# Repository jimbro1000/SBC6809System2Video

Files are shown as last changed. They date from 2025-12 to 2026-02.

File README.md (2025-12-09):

# SBC6309 Video Inspired by Acorn System 2 #

This started out as a reimplementation of the Acorn system 2 teletext card.
That design quickly went in the bin in favour or something closer to the
video implementation of the BBC Model A/B or Amstrad CPC464.

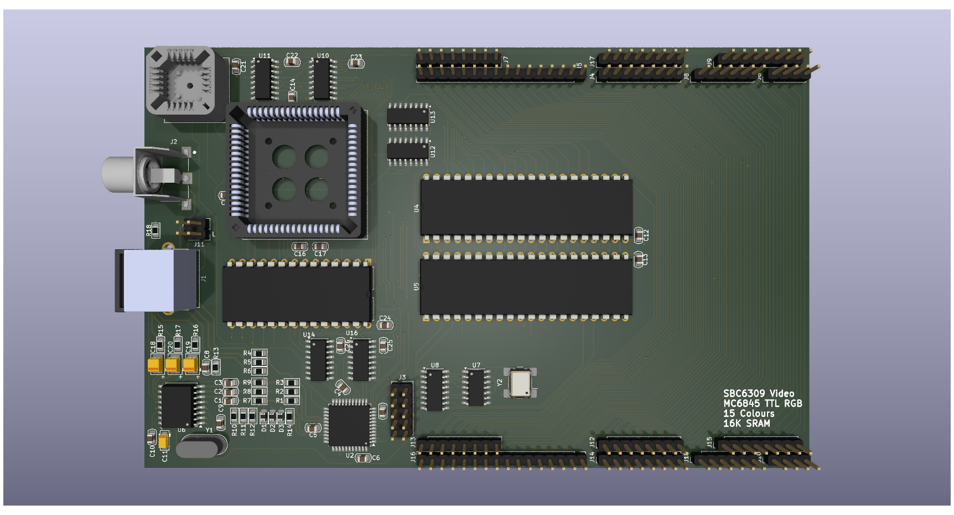
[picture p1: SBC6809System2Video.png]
Render of reproduction board


## Theory of Operation ##

The design is based around a MC6845 CRTC for video timing and sync generation.
This is supplemented with a MC6821 to provide additional control over 
variables outside of the CRTC capability (such as colour palette control)

The conversion of byte data into graphic output is handled by a small CPLD
generating TTL RGB (with a half-bright to facilitate 15 colours).

Optionally the RGB is converted to Chroma and Luma for S-video and Composite
(all in PAL format). Note the RGB doesn't have to be PAL timing but the 
composite will not operate correctly if the timing is abused. Conversion is
performed by a AD724JRZ encoder.

### Clocks ###

The pixel clock is generated on the board starting with a 32MHz oscillator,
this is divided down to 16, 8, 4 or 2MHz. At the same time the data clock is
fixed and synchronised at quarter of the pixel clock.

The choice of divider is controlled by the PIA. Changing the divider requires
the CRTC register values to be reset.

### Video Memory ###

To simplify the design the board uses 16K of dual-port SRAM, this decouples
the main clock of the computer from the video clock, allowing it to run out
of phase without repurcussions. While dual-port ram is expensive, the chip
used here can be obtained at a price comparable to regular SRAM (still more
expensive but not prohibitively so).

From the perspective of the host the video memory is just an 8K window, the
address range is paged via the PIA to expand to the full 16K.

### System Integration ###

The board uses a 16V8 GAL to integrate the board into the rest of the computer
for the purposes of mapping main bus addresses to the video ram and to the CRTC
and PIA.

The main video (RGB) output is through a 9-pin mini-din socket, this incorporates
stereo audio output not generated on this board. The signal can be injected via a
pair of two pin headers.

## Plans ##

### Text Mode ###

The objective is to create a single general purpose video board for the SBC6309
project which must include a text-only mode. To achieve this the board needs to
incorporate a character generator ROM. A set of 256 characters at 8 bytes per
character requires a 2K address space, the CRTC provides row addressing for up
to 32 bytes. Assuming the maximum the requirement increases to 8K but a 8 pixel
x 32 pixel character is of limited use. A more practical solution is to utilise
the 16 byte option and map the rows to 8, 10 or 12. An 8K rom would allow for two
different character sets, possibly at different row counts.

Switching between bitmap and character modes can be performed using a simple
74LS157 multiplexer (two required) depending on the mode. Graphic data can be mapped
to both the multiplexer directly (bitmap) or via the character rom (text).

### Larger Address Space ###

The 6845 can address a maximum of 512KB - way beyond the addressing capability
of the host. With an 8K window that 64 pages. Expanding to a 16K window would make 
this more digestable. The cost of dual-port ram would become excessive however to
take this to the maximum.

Increasing to 32K (or 64K) falls within reasonable design and cost limits.

The mechanism for expanding the address space is the same as used for text mode,
leveraging the row address registers. By adjusting the design for one, the other
becomes inherent.

Referring back to the BBC Model A/B and Amstrad CPC the same trick is used. In
the BBC the row address is effectively the lower 3 bits of the address so that
the bitmap proceeds vertically for 8 bytes before moving to the next horizontal
position. The Amstrad moves the row address on so that each row of video data
is consecutive but vertically jumps 8 rows before returning to the top (offset
by a row) and proceeding again

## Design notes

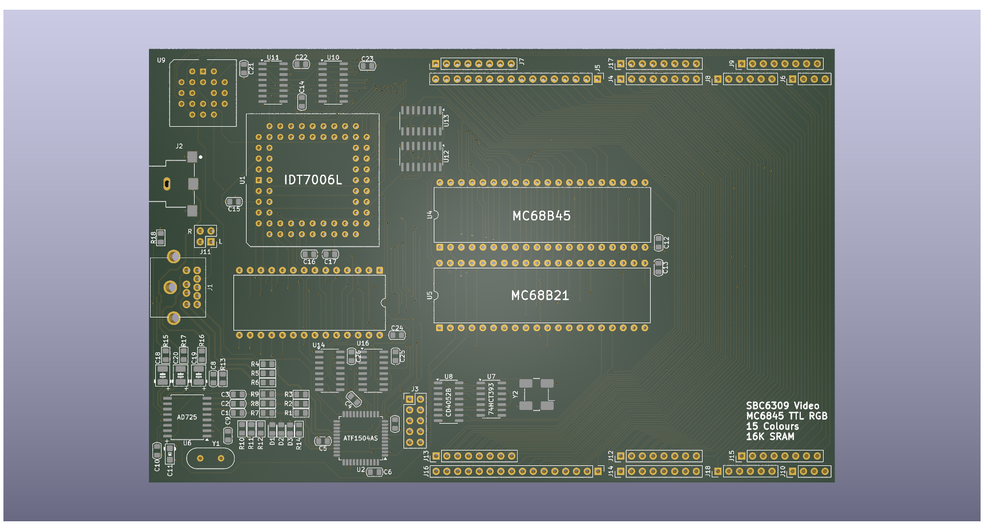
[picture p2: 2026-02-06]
SBC6809System2Video-bare.png

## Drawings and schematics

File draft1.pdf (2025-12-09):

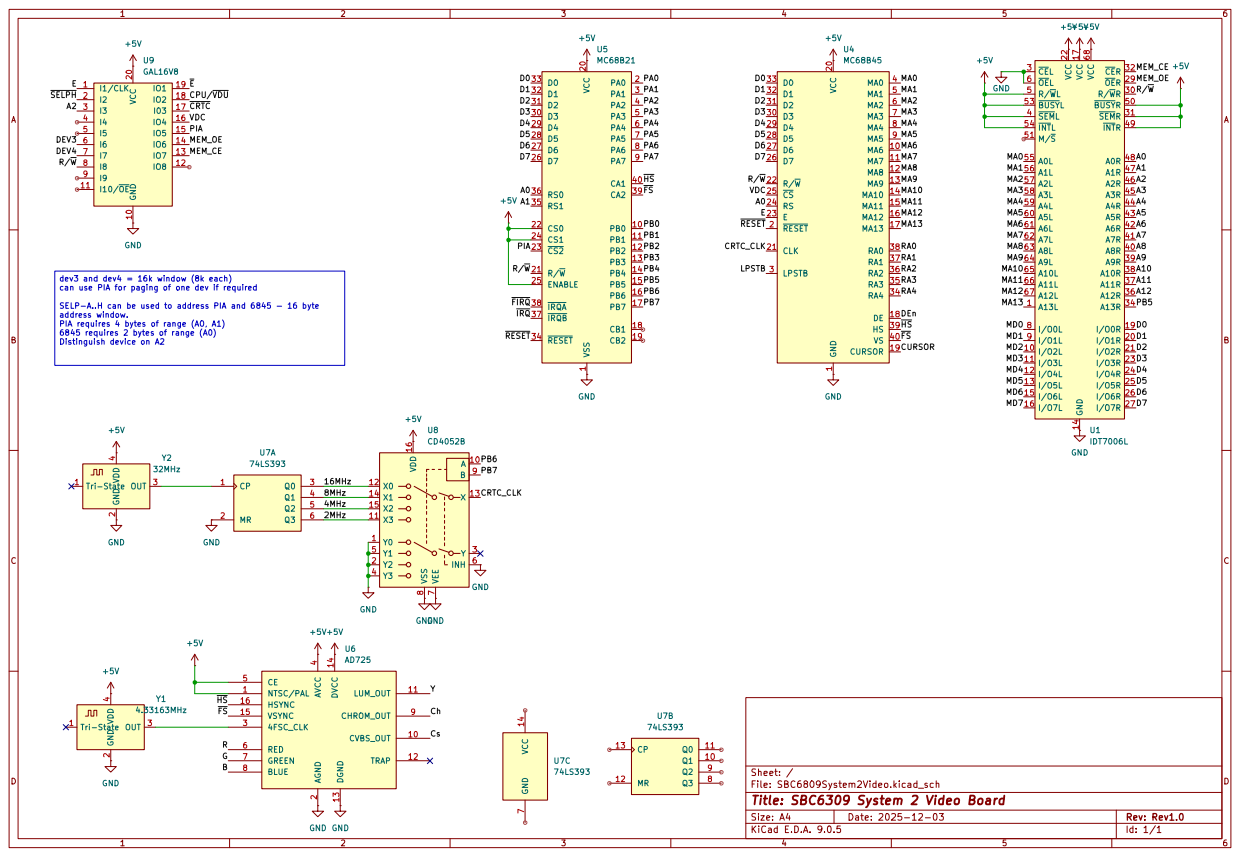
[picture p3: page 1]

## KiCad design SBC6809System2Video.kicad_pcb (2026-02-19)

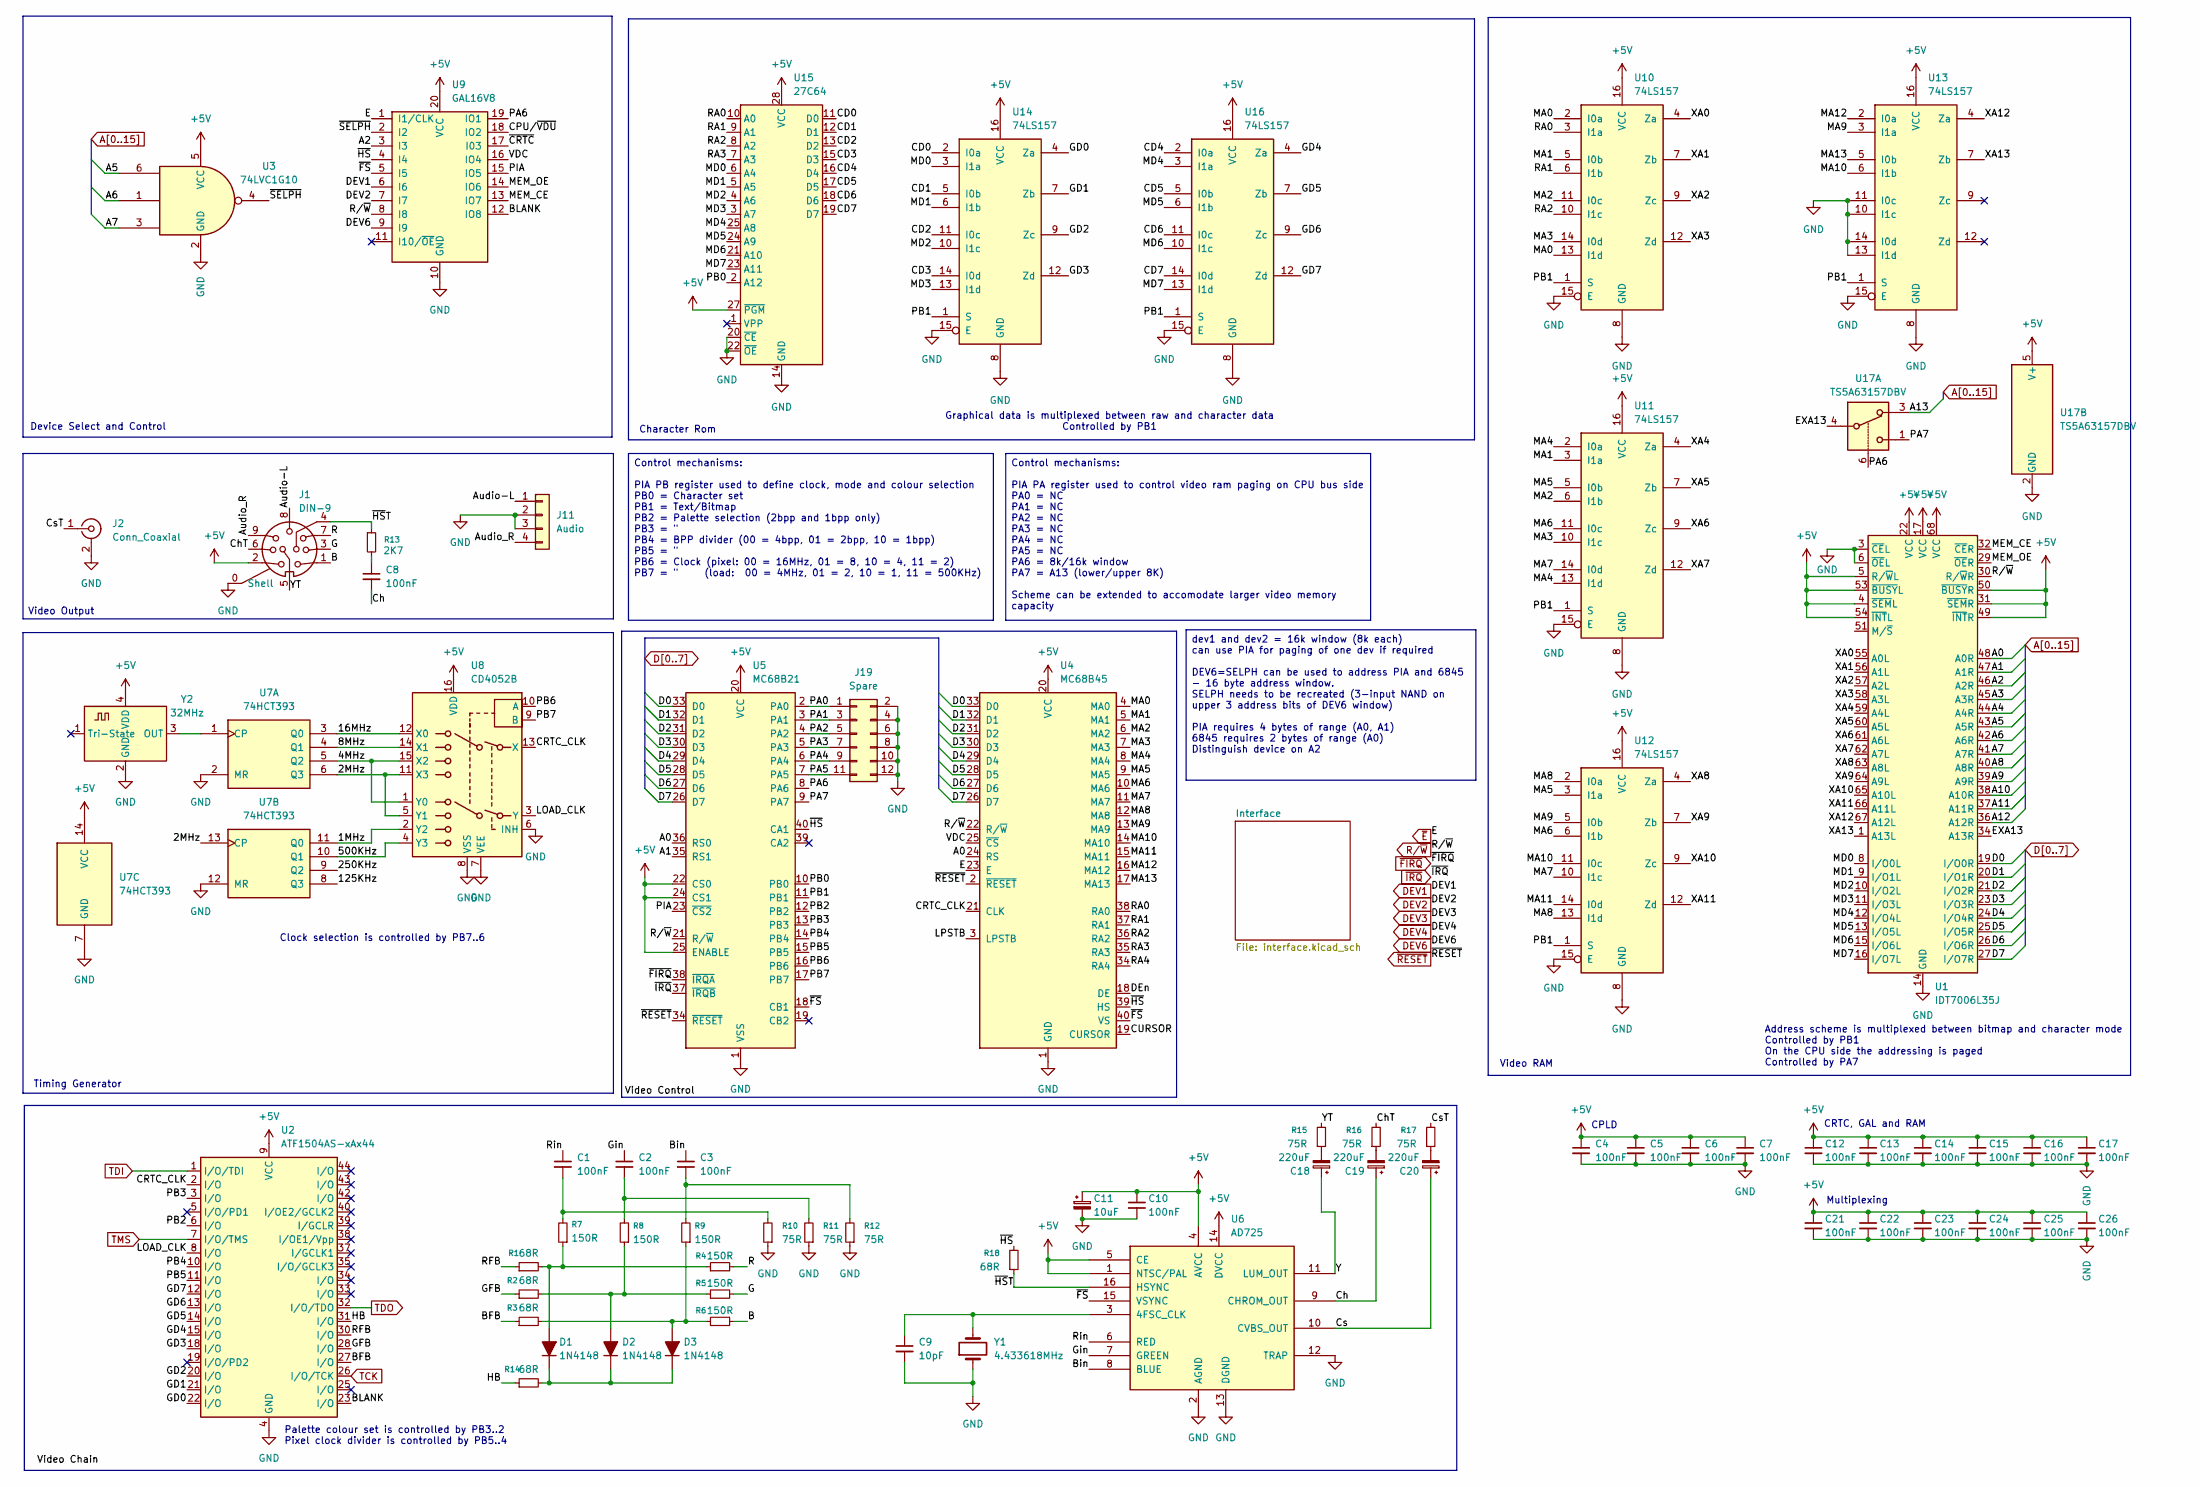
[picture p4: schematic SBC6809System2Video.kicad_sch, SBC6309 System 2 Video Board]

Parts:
C1, C2, C3, C4, C5, C6, C7, C8, C10, C12, C13, C14, C15, C16, C17, C21, C22, C23, C24, C25, C26: 100nF; C_0805_2012Metric_Pad1.15x1.40mm
C9: 10pF; C_0805_2012Metric_Pad1.15x1.40mm
C11: 10uF; CP_EIA-3216-10_Kemet-I
C18, C19, C20: 220uF; CP_EIA-3528-21_Kemet-B
D1, D2, D3: 1N4148; D_0805_2012Metric_Pad1.15x1.40mm_HandSolder
J1: DIN-9; KMDGX-9S-AS
J2: Conn_Coaxial; CUI_RCJ-013-SMT
J11: Audio; PinHeader_2x02_P2.54mm_Vertical
J19: Spare; PinSocket_2x06_P2.54mm_Vertical
R1, R2, R3, R14, R18: 68R; R_0805_2012Metric_Pad1.15x1.40mm
R4, R5, R6, R7, R8, R9: 150R; R_0805_2012Metric_Pad1.15x1.40mm
R10, R11, R12, R15, R16, R17: 75R; R_0805_2012Metric_Pad1.15x1.40mm
R13: 2K7; R_0805_2012Metric_Pad1.15x1.40mm
U1: IDT7006L35J; PLCC-68_THT-Socket
U2: ATF1504AS-xAx44; TQFP-44_10x10mm_P0.8mm
U3: 74LVC1G10; SOT-23-6_Handsoldering
U4: MC68B45; DIP-40_W15.24mm
U5: MC68B21; DIP-40_W15.24mm
U6: AD725; SOIC-16W_7.5x10.3mm_P1.27mm
U7: 74HCT393; SOIC-14_3.9x8.7mm_P1.27mm
U8: CD4052B; SOIC-16_3.9x9.9mm_P1.27mm
U9: GAL16V8; PLCC-20_THT-Socket
U10, U11, U12, U13, U14, U16: 74LS157; SOIC-16_3.9x9.9mm_P1.27mm
U15: 27C64; DIP-28_W15.24mm
U17: TS5A63157DBV; SOT-23-6
Y1: 4.433618MHz; Crystal_HC49-4H_Vertical
Y2: 32MHz; Oscillator_SMD_Abracon_ASV-4Pin_7.0x5.1mm_HandSoldering; DigiKey 110-CB3-3I-32M000000CT-ND

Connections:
+5V: C4.1, C5.1, C6.1, C7.1, C10.1, C11.1, C12.1, C13.1, C14.1, C15.1, C16.1, C17.1, C21.1, C22.1, C23.1, C24.1, C25.1, C26.1, J1.2, U1.4 (~SEML), U1.5 (R/~WL), U1.17 (VCC), U1.22 (VCC), U1.31 (~SEMR), U1.49 (~INTR), U1.50 (~BUSYR), U1.53 (~BUSYL), U1.54 (~INTL), U1.68 (VCC), U2.9 (VCC), U2.17 (VCC), U2.29 (VCC), U2.41 (VCC), U3.5 (VCC), U4.20 (VCC), U5.20 (VCC), U5.22 (CS0), U5.24 (CS1), U5.25 (ENABLE), U6.1 (NTSC/PAL), U6.4 (AVCC), U6.5 (CE), U6.14 (DVCC), U7.14 (VCC), U8.16 (VDD), U9.20 (VCC), U10.16 (VCC), U11.16 (VCC), U12.16 (VCC), U13.16 (VCC), U14.16 (VCC), U15.27 (~PGM), U15.28 (VCC), U16.16 (VCC), U17.5 (V+), Y2.4 (VDD); also elsewhere on the board
/1MHz: U7.11 (Q0), U8.2 (Y2)
/2MHz: U7.6 (Q3), U7.13 (CP), U8.5 (Y1), U8.11 (X3)
/4MHz: U7.5 (Q2), U8.1 (Y0), U8.15 (X2)
/8MHz: U7.4 (Q1), U8.14 (X1)
/16MHz: U7.3 (Q0), U8.12 (X0)
/125KHz: U7.8 (Q3)
/250KHz: U7.9 (Q2)
/500KHz: U7.10 (Q1), U8.4 (Y3)
/Audio-L: J1.8, J11.1
/Audio_R: J1.9, J11.4
/B: J1.1, R6.2
/BFB: R3.1, U2.27 (I/O)
/BLANK: U2.23 (I/O), U9.12 (IO8)
/Bin: C3.1, U6.8 (BLUE)
/CD0: U14.2 (I0a), U15.11 (D0)
/CD1: U14.5 (I0b), U15.12 (D1)
/CD2: U14.11 (I0c), U15.13 (D2)
/CD3: U14.14 (I0d), U15.15 (D3)
/CD4: U15.16 (D4), U16.2 (I0a)
/CD5: U15.17 (D5), U16.5 (I0b)
/CD6: U15.18 (D6), U16.11 (I0c)
/CD7: U15.19 (D7), U16.14 (I0d)
/CPU/~VDU: U9.18 (IO2)
/CRTC_CLK: U2.2 (I/O), U4.21 (CLK), U8.13 (X)
/CURSOR: U4.19 (CURSOR)
/Ch: C8.2, C19.1, U6.9 (CHROM_OUT)
/ChT: J1.6, R16.2
/Cs: C20.1, U6.10 (CVBS_OUT)
/CsT: J2.1 (In), R17.2
/DEn: U4.18 (DE)
/EXA13: U1.34 (A13R), U17.4
/G: J1.3, R5.2
/GD0: U2.22 (I/O), U14.4 (Za)
/GD1: U2.21 (I/O), U14.7 (Zb)
/GD2: U2.20 (I/O), U14.9 (Zc)
/GD3: U2.18 (I/O), U14.12 (Zd)
/GD4: U2.15 (I/O), U16.4 (Za)
/GD5: U2.14 (I/O), U16.7 (Zb)
/GD6: U2.13 (I/O), U16.9 (Zc)
/GD7: U2.12 (I/O), U16.12 (Zd)
/GFB: R2.1, U2.28 (I/O)
/Gin: C2.1, U6.7 (GREEN)
/HB: R14.1, U2.31 (I/O)
/LOAD_CLK: U2.8 (I/O), U8.3 (Y)
/LPSTB: U4.3 (LPSTB)
/MA0: U4.4 (MA0), U10.2 (I0a), U10.13 (I1d)
/MA1: U4.5 (MA1), U10.5 (I0b), U11.3 (I1a)
/MA2: U4.6 (MA2), U10.11 (I0c), U11.6 (I1b)
/MA3: U4.7 (MA3), U10.14 (I0d), U11.10 (I1c)
/MA4: U4.8 (MA4), U11.2 (I0a), U11.13 (I1d)
/MA5: U4.9 (MA5), U11.5 (I0b), U12.3 (I1a)
/MA6: U4.10 (MA6), U11.11 (I0c), U12.6 (I1b)
/MA7: U4.11 (MA7), U11.14 (I0d), U12.10 (I1c)
/MA8: U4.12 (MA8), U12.2 (I0a), U12.13 (I1d)
/MA9: U4.13 (MA9), U12.5 (I0b), U13.3 (I1a)
/MA10: U4.14 (MA10), U12.11 (I0c), U13.6 (I1b)
/MA11: U4.15 (MA11), U12.14 (I0d)
/MA12: U4.16 (MA12), U13.2 (I0a)
/MA13: U4.17 (MA13), U13.5 (I0b)
/MD0: U1.8 (I/O0L), U14.3 (I1a), U15.6 (A4)
/MD1: U1.9 (I/O1L), U14.6 (I1b), U15.5 (A5)
/MD2: U1.10 (I/O2L), U14.10 (I1c), U15.4 (A6)
/MD3: U1.11 (I/O3L), U14.13 (I1d), U15.3 (A7)
/MD4: U1.12 (I/O4L), U15.25 (A8), U16.3 (I1a)
/MD5: U1.13 (I/O5L), U15.24 (A9), U16.6 (I1b)
/MD6: U1.15 (I/O6L), U15.21 (A10), U16.10 (I1c)
/MD7: U1.16 (I/O7L), U15.23 (A11), U16.13 (I1d)
/MEM_CE: U1.32 (~CER), U9.13 (IO7)
/MEM_OE: U1.29 (~OER), U9.14 (IO6)
/PA0: J19.1, U5.2 (PA0)
/PA1: J19.3, U5.3 (PA1)
/PA2: J19.5, U5.4 (PA2)
/PA3: J19.7, U5.5 (PA3)
/PA4: J19.9, U5.6 (PA4)
/PA5: J19.11, U5.7 (PA5)
/PA6: U5.8 (PA6), U9.19 (IO1), U17.6
/PA7: U5.9 (PA7), U17.1
/PB0: U5.10 (PB0), U15.2 (A12)
/PB1: U5.11 (PB1), U10.1 (S), U11.1 (S), U12.1 (S), U13.1 (S), U14.1 (S), U16.1 (S)
/PB2: U2.6 (I/O), U5.12 (PB2)
/PB3: U2.3 (I/O), U5.13 (PB3)
/PB4: U2.10 (I/O), U5.14 (PB4)
/PB5: U2.11 (I/O), U5.15 (PB5)
/PB6: U5.16 (PB6), U8.10 (A)
/PB7: U5.17 (PB7), U8.9 (B)
/PIA: U5.23 (~CS2), U9.15 (IO5)
/R: J1.7, R4.2
/RA0: U4.38 (RA0), U10.3 (I1a), U15.10 (A0)
/RA1: U4.37 (RA1), U10.6 (I1b), U15.9 (A1)
/RA2: U4.36 (RA2), U10.10 (I1c), U15.8 (A2)
/RA3: U4.35 (RA3), U15.7 (A3)
/RA4: U4.34 (RA4)
/RFB: R1.1, U2.30 (I/O)
/Rin: C1.1, U6.6 (RED)
/VDC: U4.25 (~CS), U9.16 (IO4)
/XA0: U1.55 (A0L), U10.4 (Za)
/XA1: U1.56 (A1L), U10.7 (Zb)
/XA2: U1.57 (A2L), U10.9 (Zc)
/XA3: U1.58 (A3L), U10.12 (Zd)
/XA4: U1.59 (A4L), U11.4 (Za)
/XA5: U1.60 (A5L), U11.7 (Zb)
/XA6: U1.61 (A6L), U11.9 (Zc)
/XA7: U1.62 (A7L), U11.12 (Zd)
/XA8: U1.63 (A8L), U12.4 (Za)
/XA9: U1.64 (A9L), U12.7 (Zb)
/XA10: U1.65 (A10L), U12.9 (Zc)
/XA11: U1.66 (A11L), U12.12 (Zd)
/XA12: U1.67 (A12L), U13.4 (Za)
/XA13: U1.1 (A13L), U13.7 (Zb)
/Y: C18.1, U6.11 (LUM_OUT)
/YT: J1.5, R15.2
/~CRTC: U9.17 (I03)
/~FS: U4.40 (VS), U5.18 (CB1), U6.15 (VSYNC), U9.5 (I5)
/~HS: R18.2, U4.39 (HS), U5.40 (CA1), U9.4 (I4)
/~HST: J1.4, R13.1, R18.1, U6.16 (HSYNC)
/~SELPH: U3.4, U9.2 (I2)
A0: U1.48 (A0R), U4.24 (RS), U5.36 (RS0); also elsewhere on the board
A1: U1.47 (A1R), U5.35 (RS1); also elsewhere on the board
A2: U1.46 (A2R), U9.3 (I3); also elsewhere on the board
A3: U1.45 (A3R); also elsewhere on the board
A4: U1.44 (A4R); also elsewhere on the board
A5: U1.43 (A5R), U3.6; also elsewhere on the board
A6: U1.42 (A6R), U3.1; also elsewhere on the board
A7: U1.41 (A7R), U3.3; also elsewhere on the board
A8: U1.40 (A8R); also elsewhere on the board
A9: U1.39 (A9R); also elsewhere on the board
A10: U1.38 (A10R); also elsewhere on the board
A11: U1.37 (A11R); also elsewhere on the board
A12: U1.36 (A12R); also elsewhere on the board
A13: U17.3; also elsewhere on the board
D0: U1.19 (I/O0R), U4.33 (D0), U5.33 (D0); also elsewhere on the board
D1: U1.20 (I/O1R), U4.32 (D1), U5.32 (D1); also elsewhere on the board
D2: U1.21 (I/O2R), U4.31 (D2), U5.31 (D2); also elsewhere on the board
D3: U1.23 (I/O3R), U4.30 (D3), U5.30 (D3); also elsewhere on the board
D4: U1.24 (I/O4R), U4.29 (D4), U5.29 (D4); also elsewhere on the board
D5: U1.25 (I/O5R), U4.28 (D5), U5.28 (D5); also elsewhere on the board
D6: U1.26 (I/O6R), U4.27 (D6), U5.27 (D6); also elsewhere on the board
D7: U1.27 (I/O7R), U4.26 (D7), U5.26 (D7); also elsewhere on the board
DEV1: U9.6 (I6); also elsewhere on the board
DEV2: U9.7 (I7); also elsewhere on the board
DEV6: U9.9 (I9); also elsewhere on the board
GND: C4.2, C5.2, C6.2, C7.2, C9.2, C10.2, C11.2, C12.2, C13.2, C14.2, C15.2, C16.2, C17.2, C21.2, C22.2, C23.2, C24.2, C25.2, C26.2, J1.0 (Shell), J2.2 (Ext), J11.2, J11.3, J19.2, J19.4, J19.6, J19.8, J19.10, J19.12, R10.1, R11.1, R12.1, U1.3 (~CEL), U1.6 (~OEL), U1.14 (GND), U1.18 (GND), U1.35 (GND), U1.52 (GND), U2.4 (GND), U2.16 (GND), U2.24 (GND), U2.36 (GND), U3.2 (GND), U4.1 (GND), U5.1 (VSS), U6.2 (AGND), U6.12 (TRAP), U6.13 (DGND), U7.2 (MR), U7.7 (GND), U7.12 (MR), U8.6 (INH), U8.7 (VEE), U8.8 (VSS), U9.10 (GND), U10.8 (GND), U10.15 (E), U11.8 (GND), U11.15 (E), U12.8 (GND), U12.15 (E), U13.8 (GND), U13.10 (I1c), U13.11 (I0c), U13.13 (I1d), U13.14 (I0d), U13.15 (E), U14.8 (GND), U14.15 (E), U15.14 (GND), U15.20 (~CE), U15.22 (~OE), U16.8 (GND), U16.15 (E), U17.2 (GND), Y1.1, Y2.2 (GND); also elsewhere on the board
unnamed: C1.2, R7.2, R10.2
unnamed: C2.2, R8.2, R11.2
unnamed: C3.2, R9.2, R12.2
unnamed: C8.1, R13.2
unnamed: C18.2, R15.1
unnamed: C19.2, R16.1
unnamed: C20.2, R17.1
unnamed: D1.2 (A), R1.2, R4.1, R7.1
unnamed: D1.1 (K), D2.1 (K), D3.1 (K), R14.2
unnamed: D2.2 (A), R2.2, R5.1, R8.1
unnamed: D3.2 (A), R3.2, R6.1, R9.1
unnamed: C9.1, U6.3 (4FSC_CLK), Y1.2
unnamed: U7.1 (CP), Y2.3 (OUT)
R/~W: U1.30 (R/~WR), U4.22 (R/~W), U5.21 (R/~W), U9.8 (I8); also elsewhere on the board
TCK: U2.26 (I/O/TCK); also elsewhere on the board
TDI: U2.1 (I/O/TDI); also elsewhere on the board
TDO: U2.32 (I/O/TDO); also elsewhere on the board
TMS: U2.7 (I/O/TMS); also elsewhere on the board
~E: U4.23 (E), U9.1 (I1/CLK); also elsewhere on the board
~FIRQ: U5.38 (~IRQA); also elsewhere on the board
~IRQ: U5.37 (~IRQB); also elsewhere on the board
~RESET: U4.2 (~RESET), U5.34 (~RESET); also elsewhere on the board

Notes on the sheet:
Character Rom
Multiplexing
Video RAM
Video Output
Clock selection is controlled by PB7..6
CPLD
Graphical data is multiplexed between raw and character data Controlled by PB1
CRTC, GAL and RAM
Timing Generator
Palette colour set is controlled by PB3..2 Pixel clock divider is controlled by PB5..4
Address scheme is multiplexed between bitmap and character mode Controlled by PB1 On the CPU side the addressing is paged Controlled by PA7
Device Select and Control
Control mechanisms: PIA PB register used to define clock, mode and colour selection PB0 = Character set PB1 = Text/Bitmap PB2 = Palette selection (2bpp and 1bpp only) PB3 = " PB4 = BPP divider (00 = 4bpp, 01 = 2bpp, 10 = 1bpp) PB5 = " PB6 = Clock (pixel: 00 = 16MHz, 01 = 8, 10 = 4, 11 = 2) PB7 = " 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
dev1 and dev2 = 16k window (8k each) can use PIA for paging of one dev if required DEV6=SELPH can be used to address PIA and 6845 - 16 byte address window. SELPH needs to be recreated (3-input NAND on upper 3 address bits of DEV6 window) PIA requires 4 bytes of range (A0, A1) 6845 requires 2 bytes 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
Control mechanisms: PIA PA register used to control video ram paging on CPU bus side PA0 = NC PA1 = NC PA2 = NC PA3 = NC PA4 = NC PA5 = NC PA6 = 8k/16k window PA7 = A13 (lower/upper 8K) Scheme can be extended to accomodate larger video memory capacity

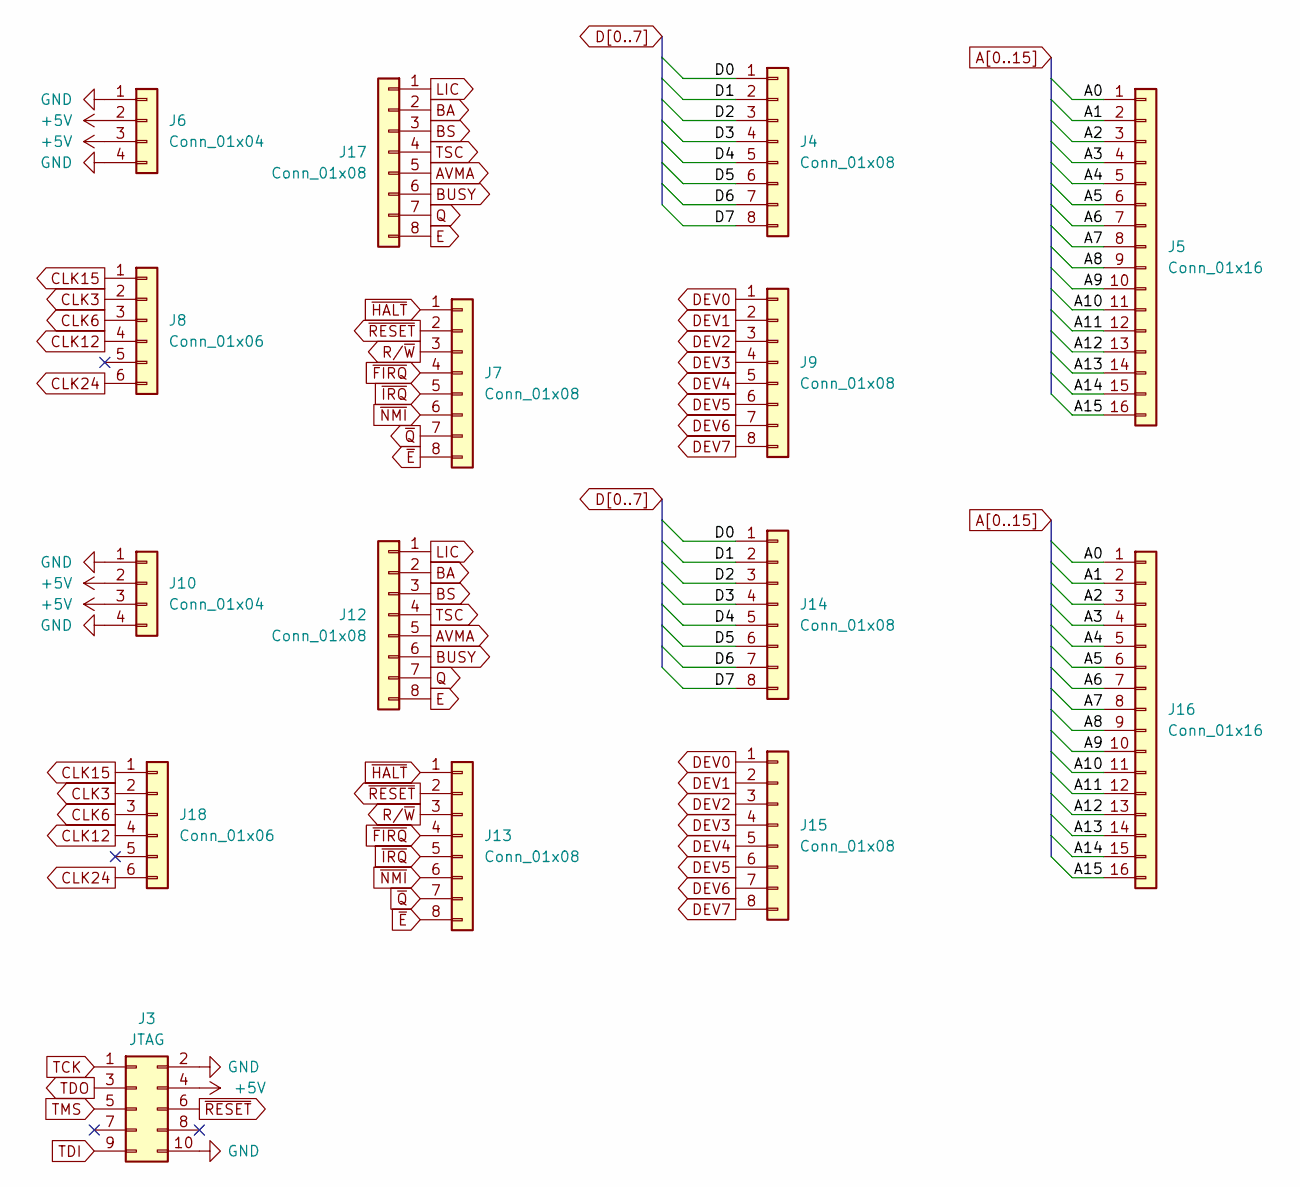
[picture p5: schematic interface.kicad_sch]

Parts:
J3: JTAG; PinHeader_2x05_P2.54mm_Vertical
J4, J7, J9, J12, J13, J14, J15, J17: Conn_01x08; PinHeader_1x08_P2.54mm_Vertical
J5, J16: Conn_01x16; PinHeader_1x16_P2.54mm_Vertical
J6, J10: Conn_01x04; PinHeader_1x04_P2.54mm_Vertical
J8, J18: Conn_01x06; PinHeader_1x06_P2.54mm_Vertical

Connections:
+5V: J3.4, J6.2, J6.3, J10.2, J10.3; also elsewhere on the board
A0: J5.1, J16.1; also elsewhere on the board
A1: J5.2, J16.2; also elsewhere on the board
A2: J5.3, J16.3; also elsewhere on the board
A3: J5.4, J16.4; also elsewhere on the board
A4: J5.5, J16.5; also elsewhere on the board
A5: J5.6, J16.6; also elsewhere on the board
A6: J5.7, J16.7; also elsewhere on the board
A7: J5.8, J16.8; also elsewhere on the board
A8: J5.9, J16.9; also elsewhere on the board
A9: J5.10, J16.10; also elsewhere on the board
A10: J5.11, J16.11; also elsewhere on the board
A11: J5.12, J16.12; also elsewhere on the board
A12: J5.13, J16.13; also elsewhere on the board
A13: J5.14, J16.14; also elsewhere on the board
A14: J5.15, J16.15
A15: J5.16, J16.16
AVMA: J12.5, J17.5
BA: J12.2, J17.2
BS: J12.3, J17.3
BUSY: J12.6, J17.6
CLK3: J8.2, J18.2
CLK6: J8.3, J18.3
CLK12: J8.4, J18.4
CLK15: J8.1, J18.1
CLK24: J8.6, J18.6
D0: J4.1, J14.1; also elsewhere on the board
D1: J4.2, J14.2; also elsewhere on the board
D2: J4.3, J14.3; also elsewhere on the board
D3: J4.4, J14.4; also elsewhere on the board
D4: J4.5, J14.5; also elsewhere on the board
D5: J4.6, J14.6; also elsewhere on the board
D6: J4.7, J14.7; also elsewhere on the board
D7: J4.8, J14.8; also elsewhere on the board
DEV0: J9.1, J15.1
DEV1: J9.2, J15.2; also elsewhere on the board
DEV2: J9.3, J15.3; also elsewhere on the board
DEV3: J9.4, J15.4
DEV4: J9.5, J15.5
DEV5: J9.6, J15.6
DEV6: J9.7, J15.7; also elsewhere on the board
DEV7: J9.8, J15.8
E: J12.8, J17.8
GND: J3.2, J3.10, J6.1, J6.4, J10.1, J10.4; also elsewhere on the board
LIC: J12.1, J17.1
Q: J12.7, J17.7
R/~W: J7.3, J13.3; also elsewhere on the board
TCK: J3.1; also elsewhere on the board
TDI: J3.9; also elsewhere on the board
TDO: J3.3; also elsewhere on the board
TMS: J3.5; also elsewhere on the board
TSC: J12.4, J17.4
~E: J7.8, J13.8; also elsewhere on the board
~FIRQ: J7.4, J13.4; also elsewhere on the board
~HALT: J7.1, J13.1
~IRQ: J7.5, J13.5; also elsewhere on the board
~NMI: J7.6, J13.6
~Q: J7.7, J13.7
~RESET: J3.6, J7.2, J13.2; also elsewhere on the board

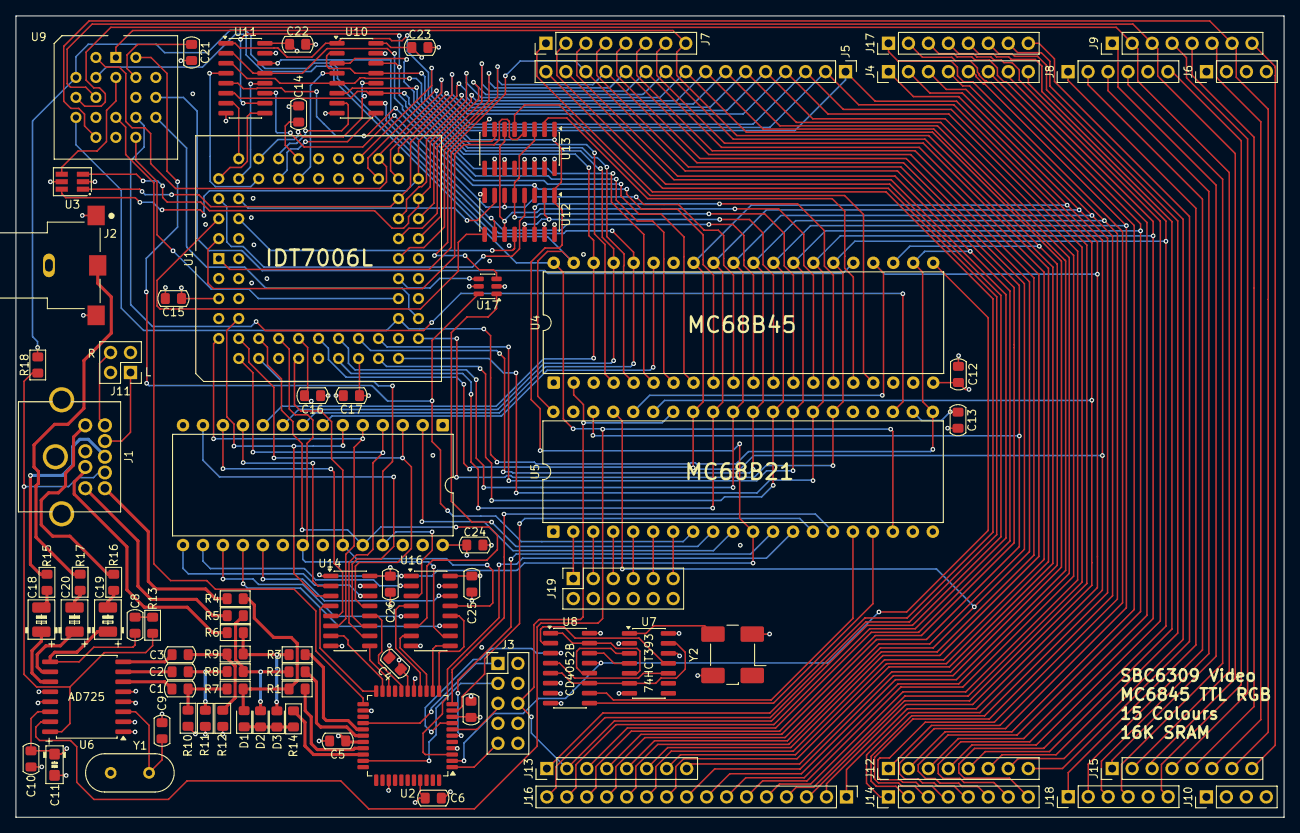
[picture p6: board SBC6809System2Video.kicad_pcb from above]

Board: 4 copper layers, 161.3 x 101.9 mm, 85 parts (0 on the bottom side), 180 nets.

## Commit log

2026-02-06 fix missing U3
    [SBC6809System2Video.kicad_pcb]
2026-02-19 update fabrication details
    [SBC6809System2Video.kicad_pcb, SBC6809System2Video.kicad_sch]
